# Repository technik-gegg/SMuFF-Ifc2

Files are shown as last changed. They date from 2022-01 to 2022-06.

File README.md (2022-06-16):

# Welcome to the SMuFF-Ifc2 project

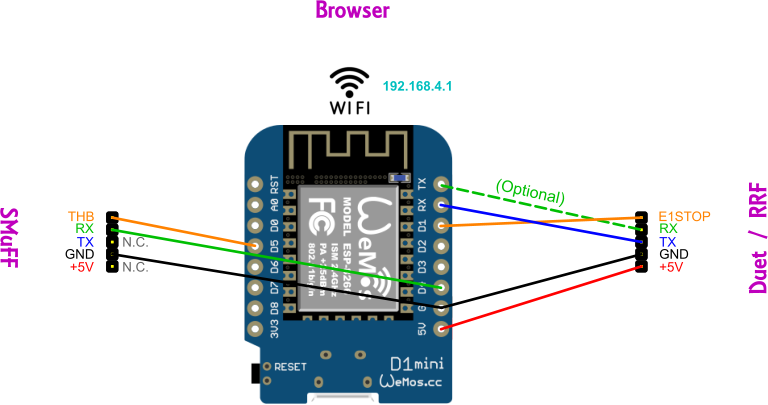
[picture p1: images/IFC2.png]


This is the firmware source code for SMuFF-Ifc2, which is used in the [SMuFF project](https://github.com/technik-gegg/SMuFF-1.1).
The IFC2 is a cheaper and simpler version of the [SMuFF-Ifc](https://github.com/technik-gegg/SMuFF-Ifc), which was built upon an ESP32 (NodeMCU) device.

In contrast to the SMuFF-Ifc, this project uses an ESP8266 (Wemos D1 mini) as the controller and since it has less capabilities, it's simpler to build and also cheaper.
The main purpose of using this interface is to add an amplifier for the serial communication lines (which can cause problems sometimes if connected directly) and also to achieve filtering of some of the data sent to the SMuFF.

---

# How to build

As you can see in the picture on top, the wiring is pretty simple and can be achieved by soldering the cables directly to the D1 mini board. Although, I'd recommend using some perfboard to do the wiring and add decent JST-XH connectors where the cables coming from SMuFF and Duet/RRF easily plug in, i.e.:

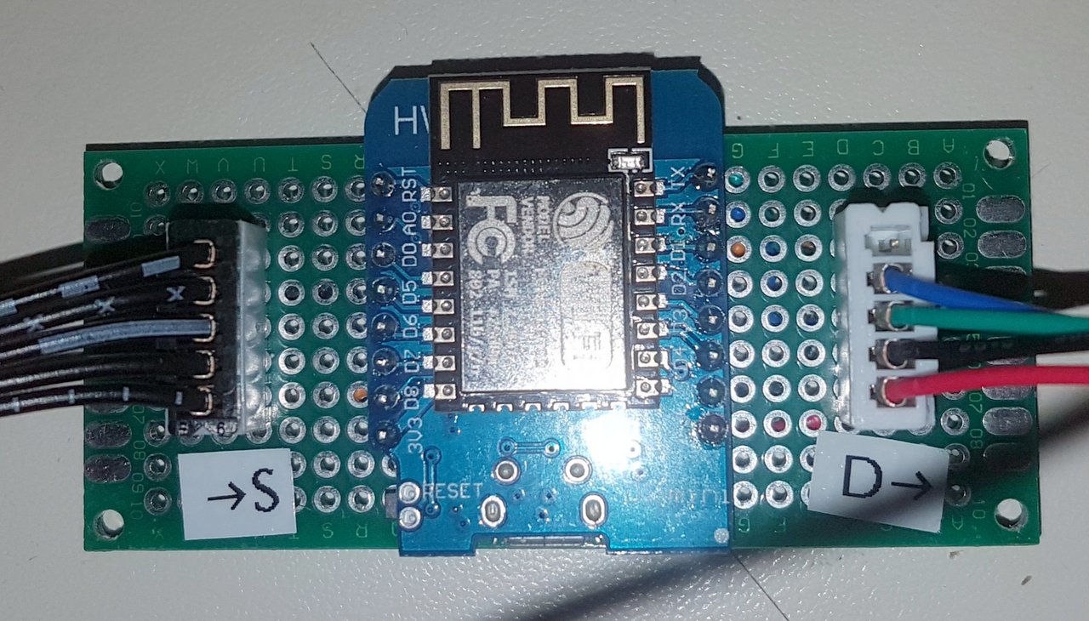
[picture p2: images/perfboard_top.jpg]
Perfboard Top

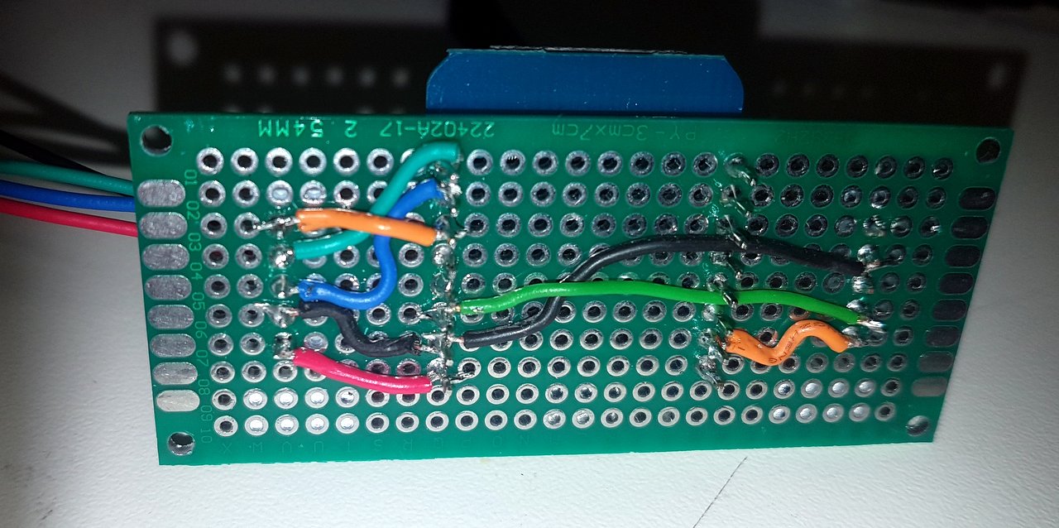
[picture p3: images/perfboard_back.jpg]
Perfboard Bottom


>**Pro tip:**
>
>If you don't want/have a perfboard, you have the option of soldering the headers using some extension wires directly to the WEMOS D1 mini pins.
>
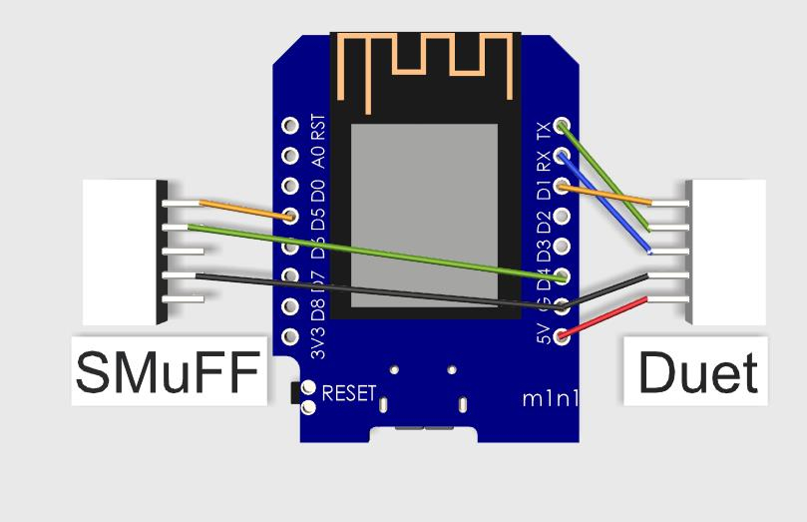
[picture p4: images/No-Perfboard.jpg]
No Perfboard
>
This way, you'll still have a detachable solution in a smaller form factor. Print a decent housing for it and you're golden!

As you can see, I've used 5-pin JST headers. I did this because the Duet/RRF needs an editional wire for an endstop, which is used to trigger the 'Busy' state of the SMuFF while it's changing tools ([details can be found here](https://sites.google.com/view/the-smuff/how-to/tutorials/configure-the-duet3d?authuser=0)). I'd suggest, you do the same.

>**Please beware:**
>
>Only the Duet/RRF board is supposed to power the Wemos D1 mini via the +5V wire. If you'd rather like the SMuFF controller to power the WEMOS D1, wire it up accordingly but make sure it's only **one device** that delivers power to the SMuFF-Ifc2.

---

# Web interface

The IFC2 utilizes the WiFi interface of the ESP8266 for debugging purpose.
To use this feature, you have to connect your PC to the *SMuFF-Ifc2_xxxxxx* WiFi hotspot once and allow the IFC2 to connect to your wireless network using the built-in [WiFiManager](https://github.com/tzapu/WiFiManager) via the static IP address **192.168.4.1**.

Once you have entered your network details and credentials, IFC2 will restart and connect to your WiFi network, which will eventually assign a new IP address to it. You can query your Router/Access Point in order to retrieve the new IP address or, use some network tool and look out for a device named **SMuFF-IFC2_xxxxxx**.

Use your browser to connect to this new address and you'll be greeted with this view:

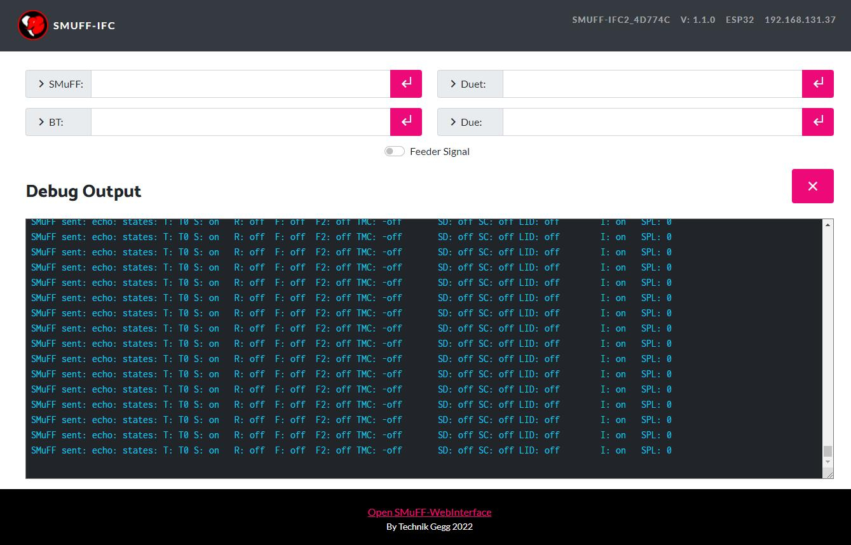
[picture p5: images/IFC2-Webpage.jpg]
Webpage


This interface will enable you to look up the debug output coming from the SMuFF-Ifc2, as well as sending GCode commands to either the SMuFF or the Duet/RRF.

*Please notice:* The input fields "BT:" and "Due:" shown in the picture above, will only show up on the ESP32 version.

>**Please keep in mind:**
>
>You'll not be able see any responses coming from the SMuFF in the *Debug Output*. That's because the ESP8266 has only the TX line available on the 2nd serial port.
>
>*In case you're curious*: This restriction is because the RX line (GPIO0) of the 2nd serial port doubles as CS pin in order to program the device via USB and therefore it's being pulled up by a resistor, which kills the receiving capabilities pretty much.
Nothing that a soldering iron and a jumper couldn't fix but it's fiddly.

If you'd like to tinker with the look and feel of this web page, the [Bootstrap Studio](https://bootstrapstudio.io/) source code is included in this repository (file *SMuFF-Ifc2.bsdesign*).

---

# Compiling / uploading

In order to compile this firmware and program it into the WEMOS D1 mini, you have to load it up in **PlatformIO** and run the *Upload* command from the **WEMOS_D1** *Project Task*.
For the very first build you also need to execute the *Upload Filesystem Image*, since the file system contains all the files needed to run the web server, as shown in the picture below.

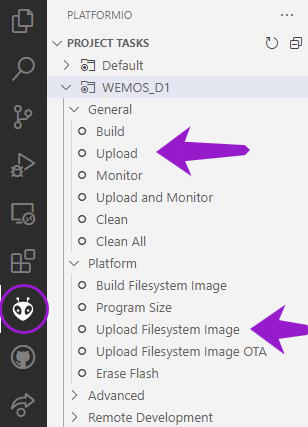
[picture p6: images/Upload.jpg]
Upload




---

# Connecting the device

As you connect the SMuFF-Ifc2 device between SMuFF and Duet/RRF, make sure you haven't accidentally crossed/shorted GND and +5V, **otherwise you will kill the device instantly!**

Connections are meant to be made between the **TFT** header on the SMuFF and the **PanelDue** (Duet) / **TFT** (SKR2, E3-RRF) header, as shown in the picture down below. More on that topic you'll find [in this write up](https://sites.google.com/view/the-smuff/how-to/tutorials/configure-the-duet3d?authuser=0).

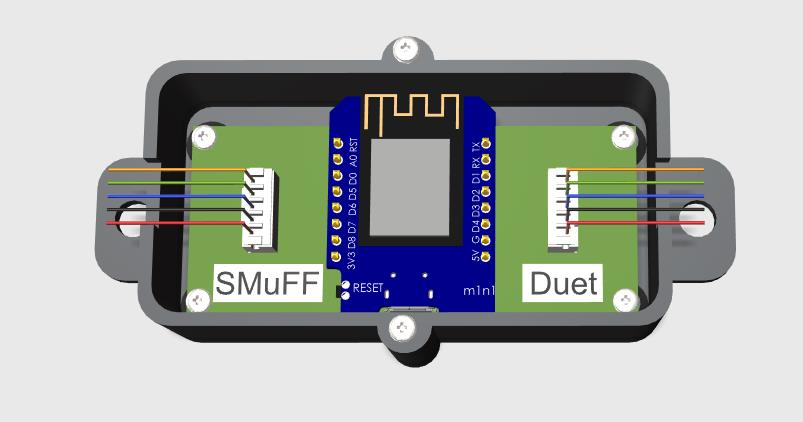
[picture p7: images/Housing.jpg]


Cables are using a 1:1 connection, except for the first pin (which is RESET on the SMuFF controller, btw.). This one is supposed to connect to the **THB** signal pin on the SMuFF and the **E1STOP** signal input on the Duet (or **E1DET** on SKR2, **PWRDET** on E3-RRF).
Always use proper connectors, i.e. **JST-XH** for the E3-DIP, SKR2 controller, **Dupont** on the E3 V2.0, E3-RRF and **Molex KK** on the Duet3D controller board series.

>**Please notice:**
>
>The RX signal on the Duet/RRF side is optional because it's not really needed for the communication between SMuFF and Duet/RRF. You'll only need it if you're going to send commands from the web interface to the Duet/RRF for testing / debugging purposes.
>
>**Also:**
>Make sure both controllers serial interfaces (SMuFF and Duet/RRF) are being configured for a baud rate of **115200** baud, since this is the (hardcoded) value in the SMuFF-Ifc2 firmware.
If you need other baudrates, you have to change it in the firmware source code - see *Config.h* - of the SMuFF-Ifc2,  re-compile and re-upload the firmware.

---

# ESP32 Notes

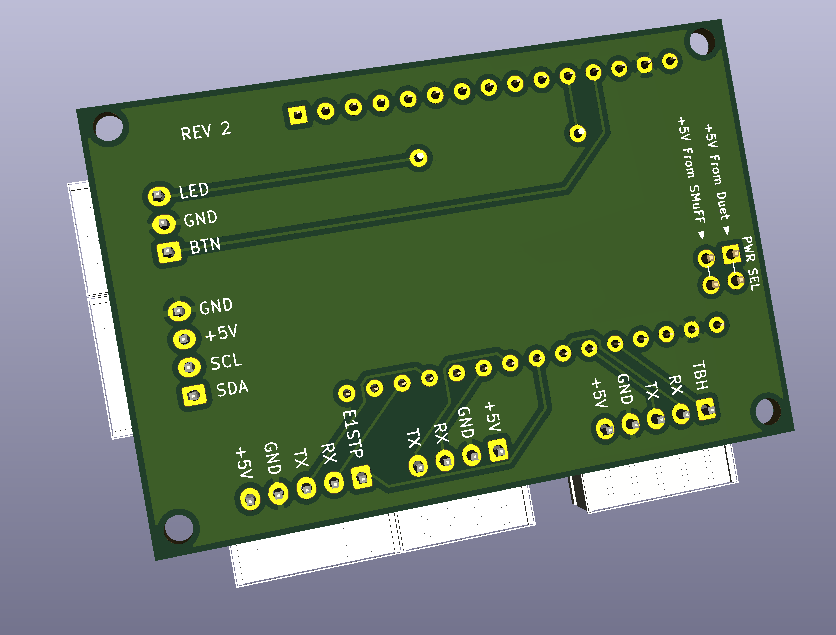
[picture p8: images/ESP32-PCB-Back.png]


The signal names on the bottom layer of this PCB depict to which pin on the according device to connect to. The PCB has been designed to allow a 1:1 connection between the device and this PCB (except pin 1). In some cases (i.e. Duet3D) you have to swap wires (see pictures down below).
No need to mention, it's always worth checking out the pin assignment of your controller (SMuFF, RRF, Duet, ...) before you attach any cable.
In any case, make sure that the power lines, +5V and GND, are going to matching pins on your controller. **Swapping them accidentally will cause harm to your controller boards!**

If you're attaching an OLED display for debugging purposes, please check the pin assignment on the OLED PCB twice. Some displays do have swapped +5V and GND pins on their connector! **Swapping them will most likley destroy your display.**

**Please notice:** *Before you connect this PCB to your devices, please make sure you've set a jumper cap on **PWR SEL** to either "+5V From Duet" **or** "+5V From SMuFF". This jumper allows you to select the power source for the ESP32 (and the OLED display, if attached). Keep in mind: It's either the one or the other, not both!*

## Setting up the wires for the ESP32-PCB

The first pin on the SMuFF header (referred to as THB) needs to be routed to the according header on the SMuFF controller and **not** to pin 1 of the TFT header (that's the *Reset* signal, which is not of much help here). Same applies to the pin 1 of the Duet/RRF header (referred to as E1STP).
In the pictures down below, please notice the difference between an SKR-RRF and genuine Duet3D boards:

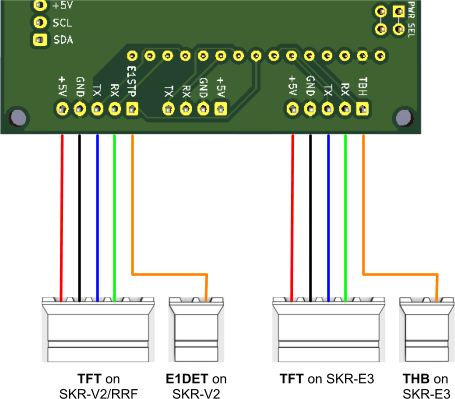
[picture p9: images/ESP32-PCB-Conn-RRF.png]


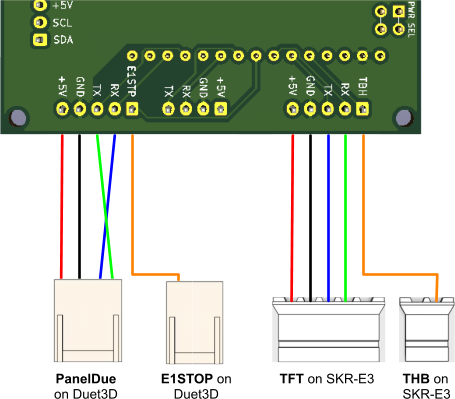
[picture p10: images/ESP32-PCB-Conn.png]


If you're going to connect a PanelDue (for the Duet3D/RRF) or another serial display (RRF only), please make sure the display is also wired up correctly, i.e.:

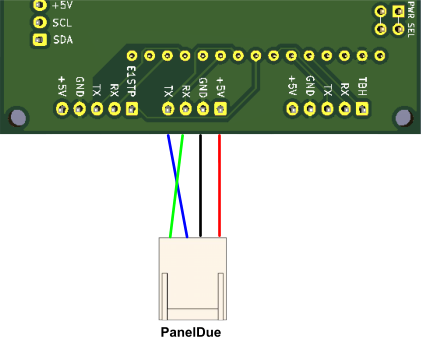
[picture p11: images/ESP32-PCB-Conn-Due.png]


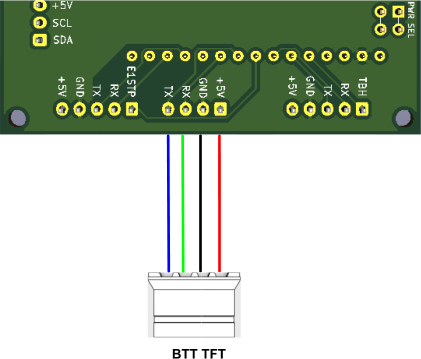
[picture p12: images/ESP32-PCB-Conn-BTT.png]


>**Pro Tip:** I'm always using the same coloring scheme as shown above, if any possible.
Means: Red for +5V (or VCC in general), black for GND (red/black for power is kind of a standard in micro electronics), blue for TX (or *output* pins in general), green for RX (or *input* pins in general) and orange / brown / white / violet / gray for other signals. This way they're easy to distinguish and it's easy to tell which wire is supposed to do what, simply by looking at its color.

---

## Recent changes

**1.2.0** - Using latest ESP32 framework

In the latest framework for the ESP32 the toolchain used did change and hence, the ESP32 version may not compile or run correctly (webpage doesn't show up for example).
I moved to the latest framework now, which doesn't show the issue (*serveStatic()* method not working correctly) anymore, as reported in 1.1.0.
I've also modified the serial port handling, which in the last version had the tendency to drop data when passing them between the serial interfaces and trying to log them on the webpage simultanously.
This version also got a *WebSocket* integration, which will be used to communicate actively with the webpage in an upcoming release.

**1.1.1** - Added Schematic and PCB for ESP32 version

This little adapter PCB for the ESP32 DevKit / NodeMCU makes wiring up all the connectors a breeze.

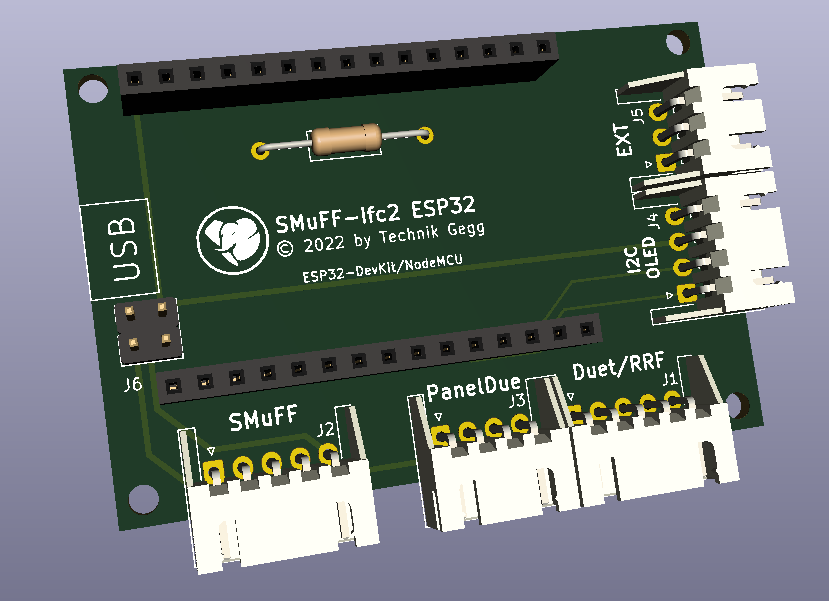
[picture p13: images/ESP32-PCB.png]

IFC2

**1.1.0** - Added ESP32 support

The ESP32 (which has been the base for SMuFF-Ifc version 1) is the bigger brother of the ESP8266 and comes with more features, such as more serial interfaces and Bluetooth support. This enables you to use the SMuFF-Ifc as an three way splitter sitting between Duet / RRF, SMuFF and PanelDue. In addition, this device supports the SMuFF WebInterface (SMuFF-WI) when connecting via Bluetooth.
With this release, the SMuFF-Ifc version 1 has become obsolete.

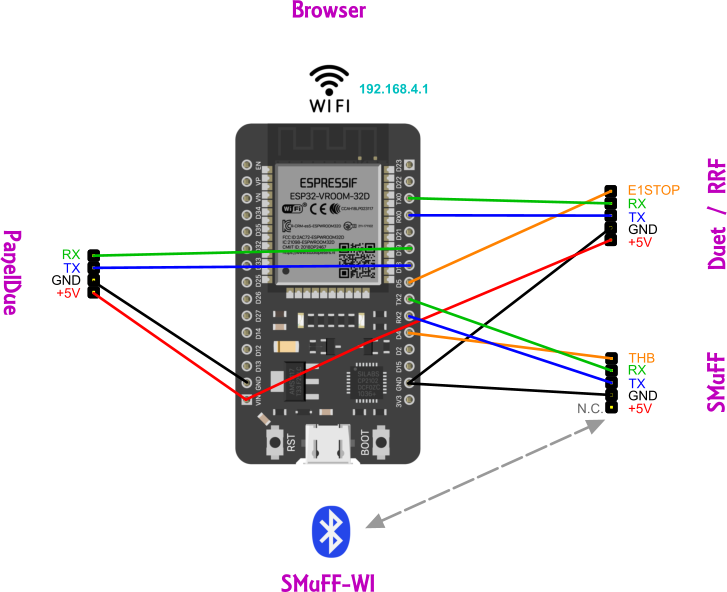
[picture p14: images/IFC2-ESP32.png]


For debugging and future enhancements, the ESP32 version also comes with the option to be equipped with an OLED (I2C) display and an addtional button / LED.

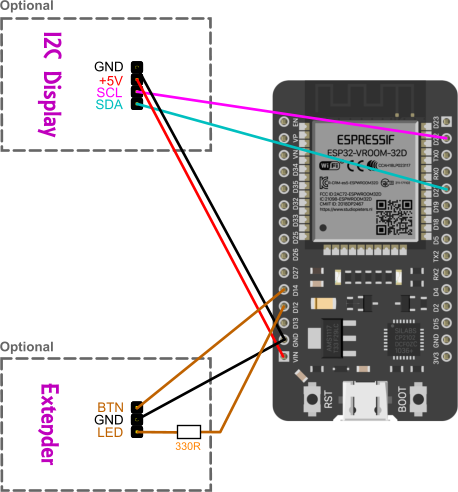
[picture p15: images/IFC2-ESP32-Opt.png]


In order to compile for the ESP32, simply pick the **ESP32_Dev** Build Environment and proceed as stated in the description above.

>**Please beware**:
>
>The *serveStatic()* method on the ESP32 isn't working correctly because of [this issue](https://github.com/espressif/arduino-esp32/issues/6172)!
Thus, the web page doesn't load up correctly in your browser.
>
>In order to fix this issue, there's a quick & dirty approach, which  modifies code in the arduino-esp32 platform source. More specificly, the **_isFile = fs.exists(path);** statement needs to be replaced with **_isFile = (strrchr(path, '.') != nullptr);**, i.e.:

```CPP
class StaticRequestHandler : public RequestHandler {
public:
    StaticRequestHandler(FS& fs, const char* path, const char* uri, const char* cache_header)
    : _fs(fs)
    , _uri(uri)
    , _path(path)
    , _cache_header(cache_header)
    {
        // quick & dirty solution for issue #6172
        //_isFile = fs.exists(path);  <-- comment out this line
        _isFile = (strrchr(path, '.') != nullptr); // <-- insert this line
        log_v("StaticRequestHandler: path=%s uri=%s isFile=%d, cache_header=%s\r\n", path, uri, _isFile, cache_header ? cache_header : ""); // issue 5506 - cache_header can be nullptr
        _baseUriLength = _uri.length();
    }
```

>**Also:** This variant utilizes the latest Arduino libraries (2.0.2) and some beta platform code, which is supposed to be released in the near future.
>
>Because of this (beta), there's a known issue with the WiFiManager, not being able to connect the device to your WiFi network via its standard user interface. A valid work around is to enter the AP-Name and credentials manually in an *wifisave* request, i.e.:
>
>http://192.168.4.1/wifisave?s={SSID}&p={PWD}
>
>Replace **{SSID}** with the name of your WiFi network/Access-Point and **{PWD}** with the assoiciated password. After sending this request, the ESP32 is supposed to connect flawlessly.

**1.0.0** - Initial commit

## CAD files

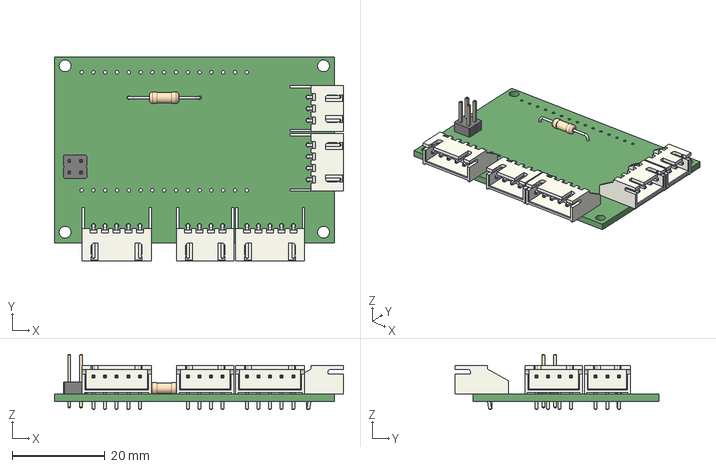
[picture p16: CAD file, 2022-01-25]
STEP/SMuFF-Ifc2-ESP32-PCB.step
62.2 x 43.9 x 11.9 mm

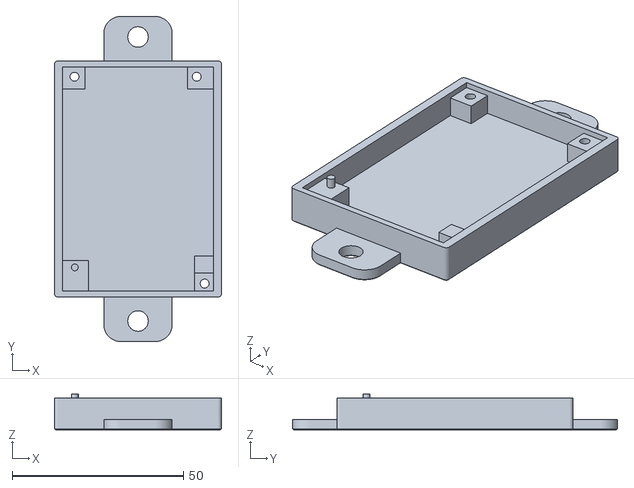
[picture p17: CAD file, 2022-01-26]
STL/Bottom-ESP32.stl
48.8 x 95.0 x 10.5

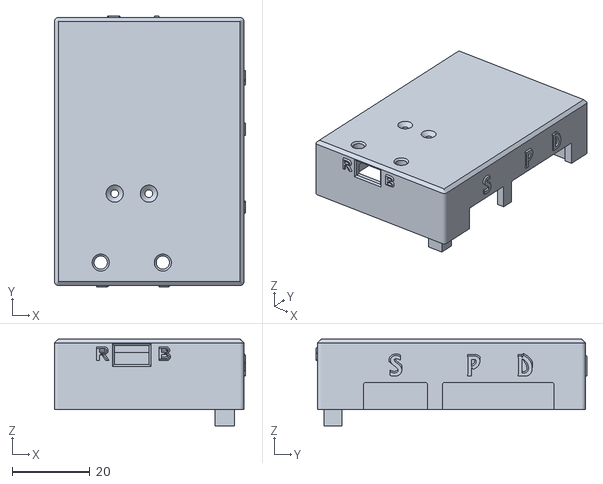
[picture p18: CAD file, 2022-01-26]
STL/Top-ESP32.stl
49.2 x 69.8 x 22.4

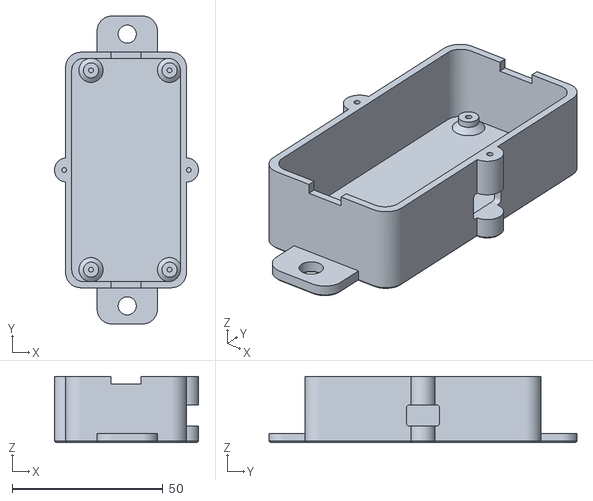
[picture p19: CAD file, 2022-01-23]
STL/Bottom.stl
47.7 x 102.0 x 22.0

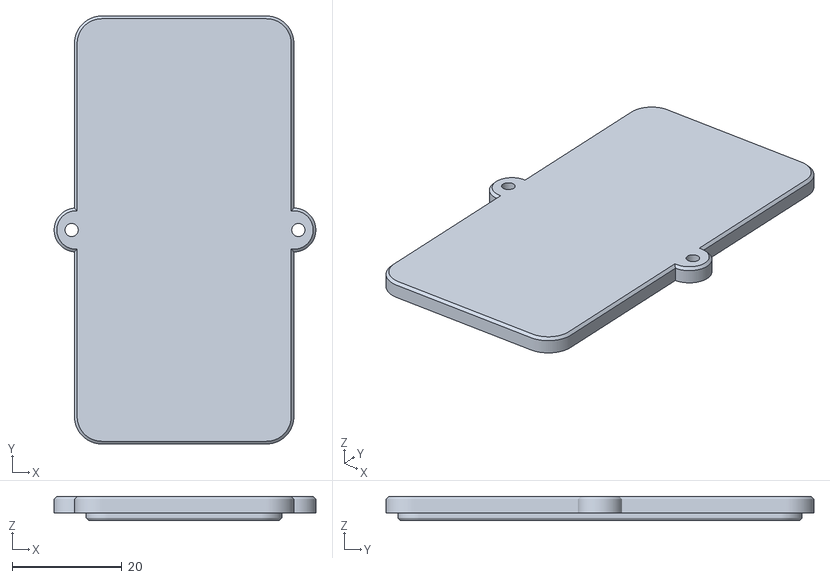
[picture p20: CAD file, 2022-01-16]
STL/Top.stl
47.7 x 78.0 x 4.40

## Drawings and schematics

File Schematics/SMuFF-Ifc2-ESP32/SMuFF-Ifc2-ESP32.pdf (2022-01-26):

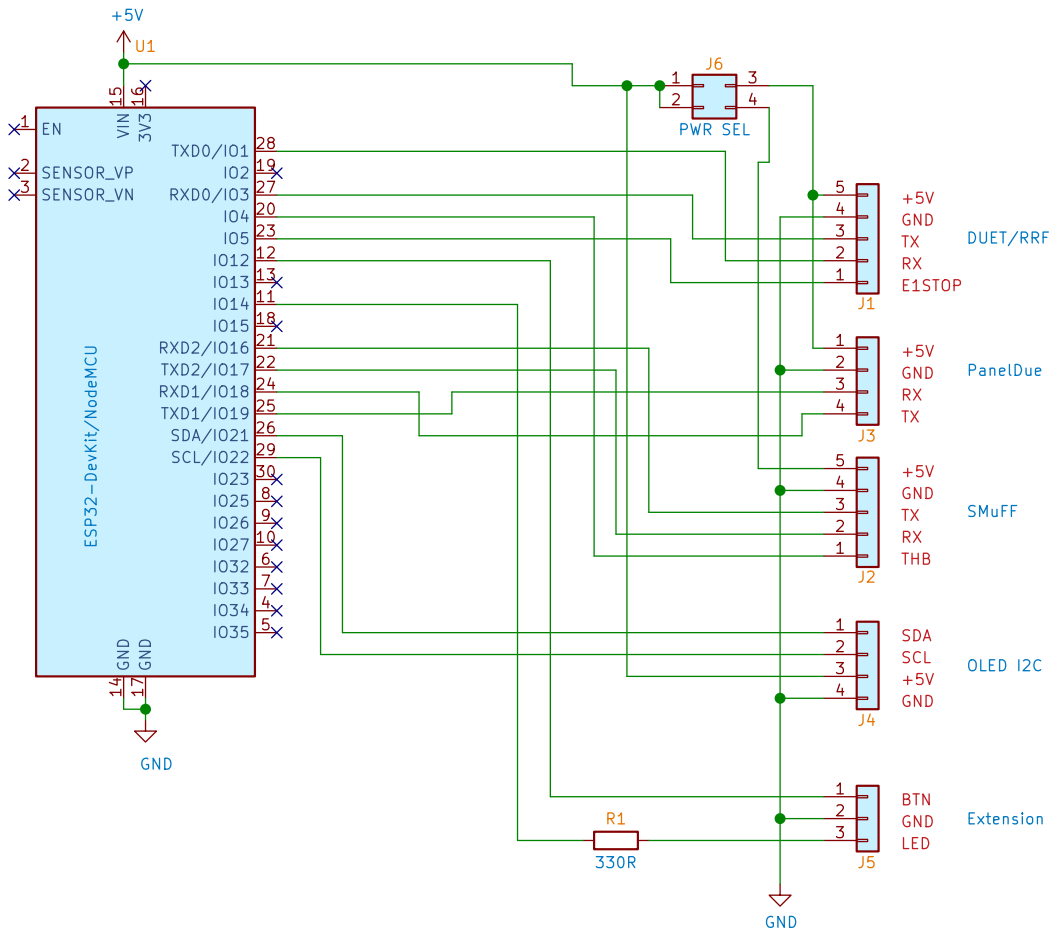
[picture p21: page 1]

File: SMuFF-Ifc2-ESP32.sch Sheet: / Technik Gegg 12345

Id: 1/1 Title: SMuFF-Ifc2 ESP32 PCB

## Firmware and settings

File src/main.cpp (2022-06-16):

/**
 * SMuFF IFC2 Firmware
 * Copyright (C) 2022 Technik Gegg
 *
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
 */
#include "Config.h"
#include <RingBuf.h>

StringStream    debugOut;

#define WM_DEBUG_PORT   (Stream&)debugOut         // route WiFiManager console messages to String
#define DEBUG_ESP_PORT  (Stream&)debugOut         // route ESP console messages to String

String          fromDuet, fromSMuFF, fromPanelDue, fromWI;
RingBuf<byte, 3072> bufFromDuet;
RingBuf<byte, 2048> bufFromSMuFF;
#if defined(ESP32)
RingBuf<byte, 1024> bufFromPanelDue;
RingBuf<byte, 512>  bufFromWI;
#endif
unsigned        millisCurrent;
unsigned        millisLast;
int             isJson = 0;
unsigned long   jsonData = 0, duetSent = 0, smuffSent = 0, dueSent = 0, btSent = 0, wiSent = 0;
bool            msgSent = false;
bool            smuffMode = false;
int             feederState = 0, buttonState = 0, btConnections = 0;
HardwareSerial  SerialDuet(0);
HardwareSerial  SerialSmuff(1);
#if defined(ESP32)
HardwareSerial  SerialDue(2);
BluetoothSerial SerialBT;
#endif

void IRAM_ATTR feederTrigger() {
  feederState = digitalRead(FEEDER_IN);
  digitalWrite(FEEDER_OUT, feederState);
  #if defined (ESP32)
  digitalWrite(LED_PIN, feederState);
  #endif
}

void sendIPAddress() {
  if(WiFi.isConnected()) {
    // Send a message to Duet
    SerialDuet.printf("M118 P0 L2 S\"SMuFF-Ifc2 has connected to network '%s'. IP-Address: %s\"\r\n", WiFi.SSID().c_str(), WiFi.localIP().toString().c_str());
  }
  else {
    SerialDuet.printf("M118 P0 L2 S\"SMuFF-Ifc2 running in AP-Mode. IP-Address: %s\"\r\n", WiFi.softAPIP().toString().c_str());
  }
}

#if defined (ESP32)
void btStatus(esp_spp_cb_event_t event, esp_spp_cb_param_t *param) {
  if (event == ESP_SPP_SRV_OPEN_EVT) {
    __debugS("Bluetooth serial connected");
    btConnections++;
  }
  else if (event == ESP_SPP_CLOSE_EVT) {
    __debugS("Bluetooth serial disconnected");
    btConnections--;
  }
}

void IRAM_ATTR buttonTrigger() {
  buttonState = digitalRead(BTN_PIN);
  // TODO: assign a function to the button trigger
}

// only available on ESP32 since on WEMOS-D1 the built in LED doubles as TX1!
void toggleIntLED() {
  digitalWrite(INTLED_PIN, !digitalRead(INTLED_PIN));
}

void flashIntLED(int repeat, int _delay) {
  for(int i=0; i<(repeat*2); i++) {
    toggleIntLED();
    delay(_delay);
  }
}

#endif

void setup(){
  #if defined(ESP32)
    esp_log_set_vprintf(__debugESP);
    initDisplay();
    __debugS("Display initialized...");
    drawScreen();
  #endif
  __debugS("SMuFF-Ifc2 Version %s (%s)\n", VERSION, MCUTYPE);
  __debugS("Starting...");


  // initialize serial ports
  #if !defined(ESP32)
    SerialDuet.begin(BAUDRATE);       // RXD0, TXD0
    SerialSmuff.begin(BAUDRATE);      // TXD1 only
    __debugS("Serial 1 & 2 initialized at %ld Baud", BAUDRATE);
  #else
    SerialDuet.begin (BAUDRATE, SERIAL_8N1, RXD0_PIN, TXD0_PIN);
    SerialSmuff.begin(BAUDRATE, SERIAL_8N1, RXD1_PIN, TXD1_PIN);
    SerialDue.begin  (BAUDRATE, SERIAL_8N1, RXD2_PIN, TXD2_PIN);
    __debugS("Serial 1, 2 & 3 initialized at %ld Baud", BAUDRATE);
  #endif

  #if defined(USE_FS)
    __debugS("Filesystem init...");
    if(LittleFS.begin()) {
      __debugS("ok");
    }
    else {
      __debugS("failed");
    }  
  #endif
  __debugS("Webserver init...");
  initWebserver();
  initWebsockets();
  drawScreen();
  
  #if defined(ESP32)
    // setup Bluetooth serial for SMuFF WebInterface connection (ESP32 only)
    SerialBT.begin(deviceName);
    SerialBT.register_callback(btStatus); 
    __debugS("Bluetooth Serial initialized");

    pinMode(BTN_PIN, INPUT_PULLUP);
    pinMode(LED_PIN, OUTPUT);
    pinMode(INTLED_PIN, OUTPUT);
    attachInterrupt(digitalPinToInterrupt(BTN_PIN), buttonTrigger, CHANGE);
    __debugS("External I/O initialized");
  #endif

  pinMode(FEEDER_IN, INPUT);
  pinMode(FEEDER_OUT, OUTPUT);
  attachInterrupt(digitalPinToInterrupt(FEEDER_IN), feederTrigger, CHANGE);
  __debugS("Feeder I/O initialized");
  drawScreen();
  
  millisLast = millis();
  #if defined(ESP32)
    flashIntLED(5);
  #endif
}

void serialDuetEvent() {
  while (SerialDuet.available()) {
    int in = SerialDuet.read();
    if(in == -1)
      break;
    if(in == '\\') {                  // is it a escape sequence?
      while(!SerialDuet.available())  
        ;                             // wait for next character
      int nxt = SerialDuet.read();
      switch(nxt) {
        case '\\': in = '\\'; break;
        case 'n': in = '\n'; break;
        case 'r': in = '\r'; break;
        case 'a': in = '\a'; break;
        case 'b': in = '\b'; break;
        case 't': in = '\t'; break;
        case '@': in = 0;
                  sendIPAddress();    // special case for "\@"
                  continue;
        case 's': in = 0;             // smuffMode routes data to SMuFF instead to the PanelDue
                  smuffMode = true;
                  break;
        
        default:  
                  #if defined(ESP32)
                  SerialDue.write(in);
                  SerialDue.write(nxt);
                  #endif
                  continue;
      }
    }
    if(in != 0) {
      #if defined(ESP32)
      if(smuffMode) {
        SerialSmuff.write(in);
      }
      else {
        SerialDue.write(in);
      }
      #else
        // filter any JSON sequences coming from Duet since SMuFF won't handle it
        if(in == '{') {
          isJson++;
        }
        if(in == '}') {
          isJson--;
          fromDuet += in;
          continue;
        }
        if(isJson <= 0) {
          if(in != 0)
            SerialSmuff.write(in);
        }
      #endif
      bufFromDuet.lockedPush(in);
    }
  }
}

void serialSmuffEvent() {
  while (SerialSmuff.available()) {
    int in = SerialSmuff.read();
    if(in == -1)
      break;
    #if defined(ESP32)
      if(btConnections > 0)
        SerialBT.write(in);
    #endif
    bufFromSMuFF.lockedPush(in);
  }
}

#if defined(ESP32)
void SerialDueEvent() {
  while (SerialDue.available()) {
    int in = SerialDue.read();
    if(in == -1)
      break;
    SerialDuet.write(in);
    bufFromPanelDue.lockedPush(in);
  }
}

void serialBTEvent() {
  while (SerialBT.available()) {
    int in = SerialBT.read();
    if(in == -1)
      break;
    SerialSmuff.write(in);
    bufFromWI.lockedPush(in);
  }
}

// just for the laughs...
void goToHall() {
  int hall;
  if((hall = hallRead()) > 150) {
    long r = random(6);
    switch(r) {
      case 0: __debugS("What the Hall?"); break;
      case 1: __debugS("What are you up to?"); break;
      case 2: __debugS("Magneto, is that you?"); break;
      case 3: __debugS("Stop tickling me!"); break;
      case 4: __debugS("You bore me..."); break;
      case 5: __debugS("Dude, let go!"); break;
      // feel free to add more stupid stuff in here (and increment the number in random above)...
    }
  }
}
#endif

template<class T>
void dumpBuffer(const T& buffer, String& ref, const char* dbg, unsigned long* cntRef, bool sendWS = false) {
    if(buffer->isEmpty())
      return;
    bool stat = true;
    bool lineComplete = false;
    do {
      byte b;
      if((stat = (bool)buffer->lockedPop(b))) {
        if(b=='\n') {
          lineComplete = true;
          break;
        }
        ref += (char)b;
      }
    } while (stat);
    if(lineComplete) {
      if(sendWS)
        sendToWebsocket(ref);
      if(dbg != nullptr)
        __debugS("%s sent: %s", dbg, ref.c_str());
      ref = "";
      *cntRef += 1;
    }
}

void loop() { 

  if(SerialDuet.available()) {
    serialDuetEvent();
  }
  if(SerialSmuff.available()) {
    serialSmuffEvent();
  }
  #if defined(ESP32)
    if(SerialDue.available()) {
      SerialDueEvent();
    }
    if(SerialBT.available()) {
      serialBTEvent();
    }
  #endif

  dumpBuffer(&bufFromSMuFF, fromSMuFF, "SMuFF", &smuffSent, true);
  dumpBuffer(&bufFromDuet, fromDuet, "Duet", &duetSent, false);
  #if defined(ESP32)
    dumpBuffer(&bufFromPanelDue, fromPanelDue, "PanelDue", &dueSent, false);
    dumpBuffer(&bufFromWI, fromWI, "SMuFF-WI", &btSent, false);
  #endif

  loopWebserver();
  
  if(millis()-millisLast > 5000) {
    // send message with IP address to Duet Log
    if(!msgSent) {
      sendIPAddress();
      msgSent = true;
    }
    millisLast = millis();
  }

  if(millis() % 500 == 0) {
    #if defined(ESP32)
      goToHall();
      drawScreen();
    #endif
  }

}

int __debugESP(const char* fmt, va_list arguments) {
  char _dbg[1024];
  int res = vsnprintf(_dbg, ArraySize(_dbg) - 1, fmt, arguments);
  debugOut.println(_dbg);
  debugOut.flush();
  return res;
}

void __debugS(const char* fmt, ...)
{
    char _dbg[2048];
    va_list arguments;
    va_start(arguments, fmt);
    vsnprintf_P(_dbg, ArraySize(_dbg) - 1, fmt, arguments);
    va_end(arguments);
    debugOut.println(_dbg);
    debugOut.flush();
    // #if defined(ESP32)
    //   drawScreen();
    // #endif
}

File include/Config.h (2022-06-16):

#pragma once

#include <Arduino.h>
#include <LittleFS.h>
#include <WiFiManager.h>
#include "StringStream.h"
#if defined(ESP32)
#include <BluetoothSerial.h>
#endif

#define VERSION         "1.2.0"
#if defined(ESP32)
#define MCUTYPE         "ESP32"
#else
#define MCUTYPE         "ESP8266"
#endif
#define USE_FS          1
#define DEBUG           1
#if defined (ESP32)
#define INTLED_PIN      2   // GPIO2 - built in LED
#define FEEDER_IN       4   // GPIO4
#define FEEDER_OUT      5   // GPIO5
#define RXD0_PIN        3   // RX0
#define TXD0_PIN        1   // TX0
#define RXD1_PIN        16  // RX2
#define TXD1_PIN        17  // TX2
#define RXD2_PIN        18  // GPIO18
#define TXD2_PIN        19  // GPIO19
#define BTN_PIN         14  // GPIO14
#define LED_PIN         12  // GPIO12
#else
#define FEEDER_IN       D5
#define FEEDER_OUT      D1
#endif
#define BAUDRATE        115200

#define ArraySize(arr) (sizeof(arr) / sizeof(arr[0]))

#define MIME_JSON       "text/json"
#define MIME_HTML       "text/html"
#define MIME_TEXT       "text/plain"

extern WiFiManager      wifiMgr;
extern int              wifiBtn;
extern char             deviceName[];
extern HardwareSerial   SerialDuet;
extern HardwareSerial   SerialSmuff;
#if defined(ESP32)
extern HardwareSerial   SerialDue;
extern BluetoothSerial  SerialBT;
#endif
extern StringStream     debugOut;
extern unsigned long    jsonData, duetSent, smuffSent, dueSent, btSent;
extern int              feederState, buttonState, btConnections;


extern void initWebserver();
extern void initWebsockets();
extern void sendToWebsocket(String& data);
extern void loopWebserver();
extern void initDisplay();
extern void resetDisplay();
extern void drawIPAddress(const char* buf);
extern void drawAP(const char* buf);
extern void drawScreen();
extern void flashIntLED(int repeat, int _delay = 300);
extern void __debugS(const char *fmt, ...);
extern int  __debugESP(const char* fmt, va_list arguments);

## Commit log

2022-01-16 Added STLs for housing
    [Bottom.stl, Top.stl]
2022-01-23 Added ESP32 support and STEP files
    [Bottom-ESP32.stl, Bottom.stl, Top-ESP32.stl]
2022-01-24 Housing mirrored (ESP32) for easier wiring
    [Bottom-ESP32.stl, Top-ESP32.stl]
2022-01-25 Added Schematic and PCB for ESP32
    [SMuFF-Ifc2-ESP32-B_Cu.gbr, SMuFF-Ifc2-ESP32-B_Mask.gbr, SMuFF-Ifc2-ESP32-B_SilkS.gbr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]
2022-01-25 Updated .gitignore
    [SMuFF-Ifc2-ESP32.kicad_pcb]
2022-01-26 Updated PCB/Schematics
    [SMuFF-Ifc2-ESP32-B_Cu.gbr, SMuFF-Ifc2-ESP32-B_Mask.gbr, SMuFF-Ifc2-ESP32-B_SilkS.gbr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]
2022-01-26 Updated Gerber files
    [SMuFF-Ifc2-ESP32-B_Cu.gbr, SMuFF-Ifc2-ESP32-B_Mask.gbr, SMuFF-Ifc2-ESP32-B_SilkS.gbr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]
2022-01-26 Updated STLs forESP32
    [Bottom-ESP32.stl, SMuFF-Ifc2-ESP32.kicad_pcb, Top-ESP32.stl]
2022-06-16 Updated to 1.1.2; See README.md
    [SMuFF-Ifc2-ESP32.kicad_pcb, custompart.csv]

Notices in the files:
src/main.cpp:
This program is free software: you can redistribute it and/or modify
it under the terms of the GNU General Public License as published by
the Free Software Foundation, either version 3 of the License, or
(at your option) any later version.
